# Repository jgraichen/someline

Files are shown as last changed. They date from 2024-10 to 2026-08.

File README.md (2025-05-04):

# Someline® Insets

3D printable insets for some Someline® storage boxes.

The insets can be used for small parts storage, such as screws or threaded inserts. Insets can easily be taken out, reorganized, spilled or refilled.

A label tab supports common 6 mm label printer tape.

You can find all models and print profiles on [MakerWorld](https://makerworld.com/en/collections/6267464).

## Someline box with 15 compartments

See: [MakerWorld](https://makerworld.com/en/models/706279) &middot; [Amazon](https://www.amazon.de/dp/B08GBPQJBG)

The insets have some tolerances to ease inserting and removing. Therefore, I recommend placing a few walls to balance spacing.

<table cellpadding="0">
  <tr>
    <td>
      <a href="docs/someline-15-empty.jpeg">
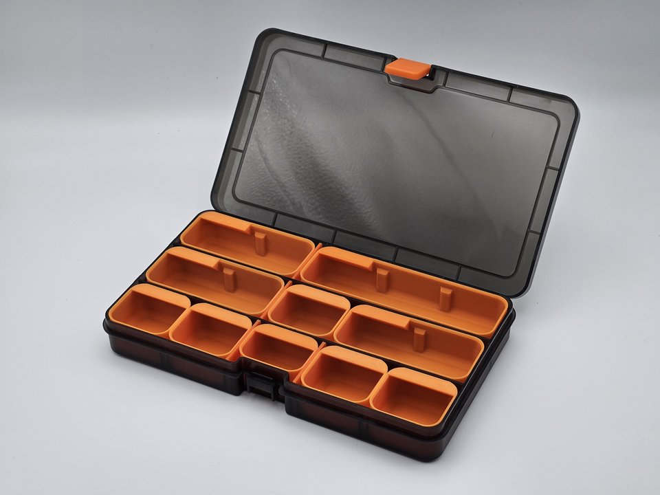
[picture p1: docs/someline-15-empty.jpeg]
        
      </a>
    </td>
    <td>
      <a href="docs/someline-15-example-1.jpeg">
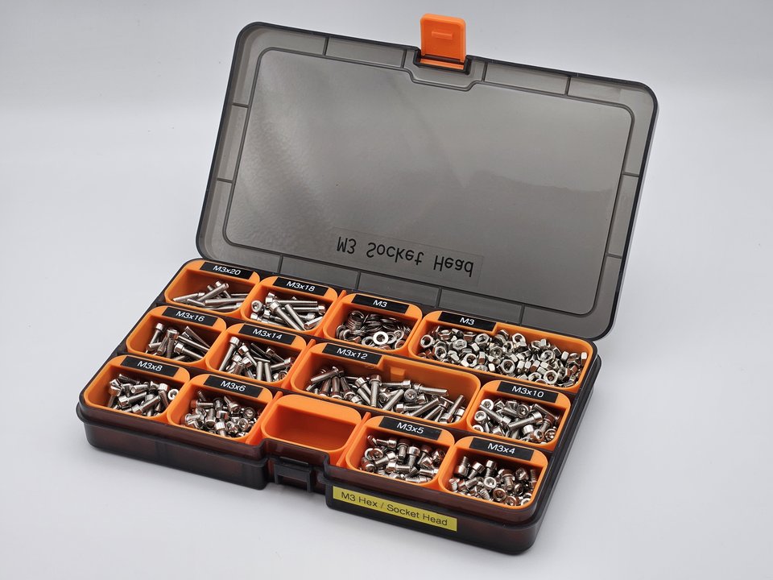
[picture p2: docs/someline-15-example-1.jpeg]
        
      </a>
    </td>
    <td>
      <a href="docs/someline-15-example-2.jpeg">
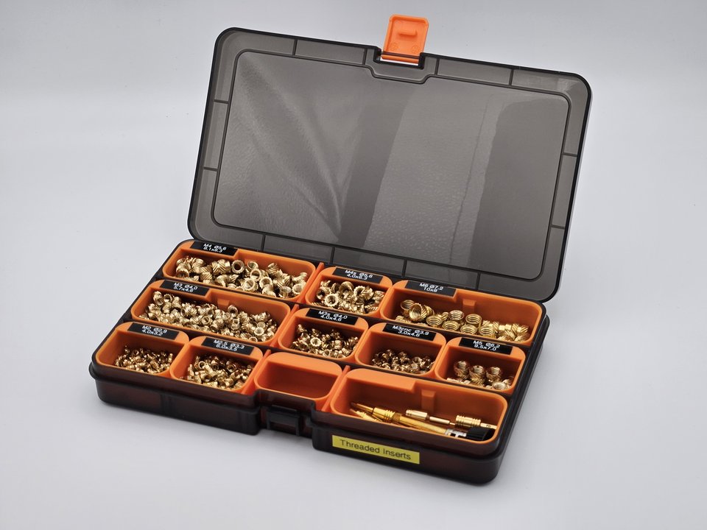
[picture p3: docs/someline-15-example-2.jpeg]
        
      </a>
    </td>
    <td>
      <a href="docs/someline-15-u.jpeg">
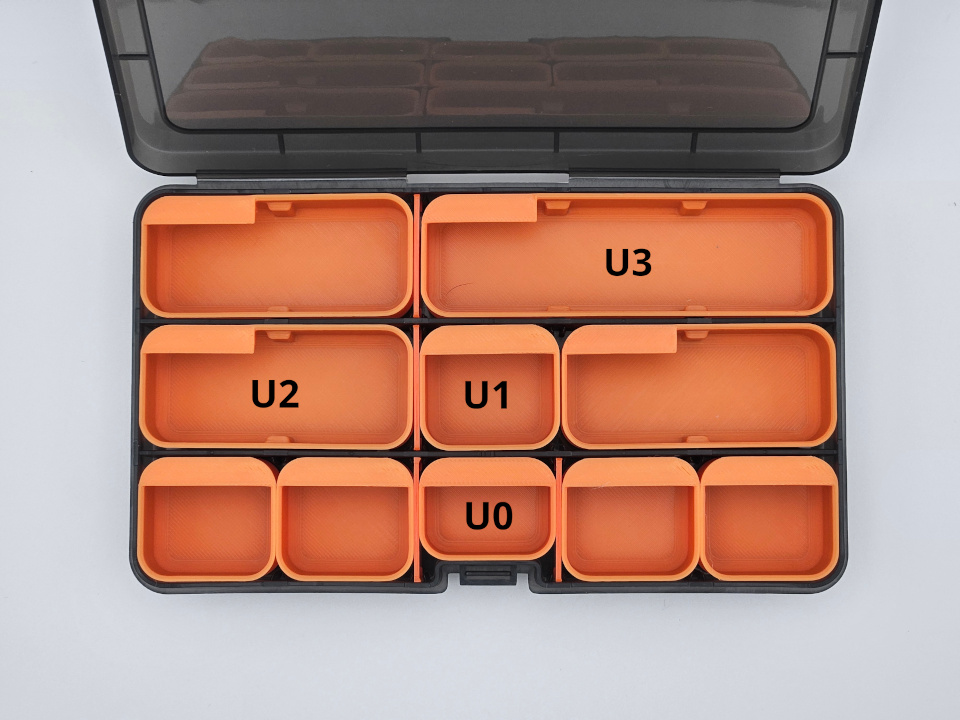
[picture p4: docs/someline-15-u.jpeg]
        
      </a>
    </td>
    <td>
      <a href="docs/someline-15-u-2.jpeg">
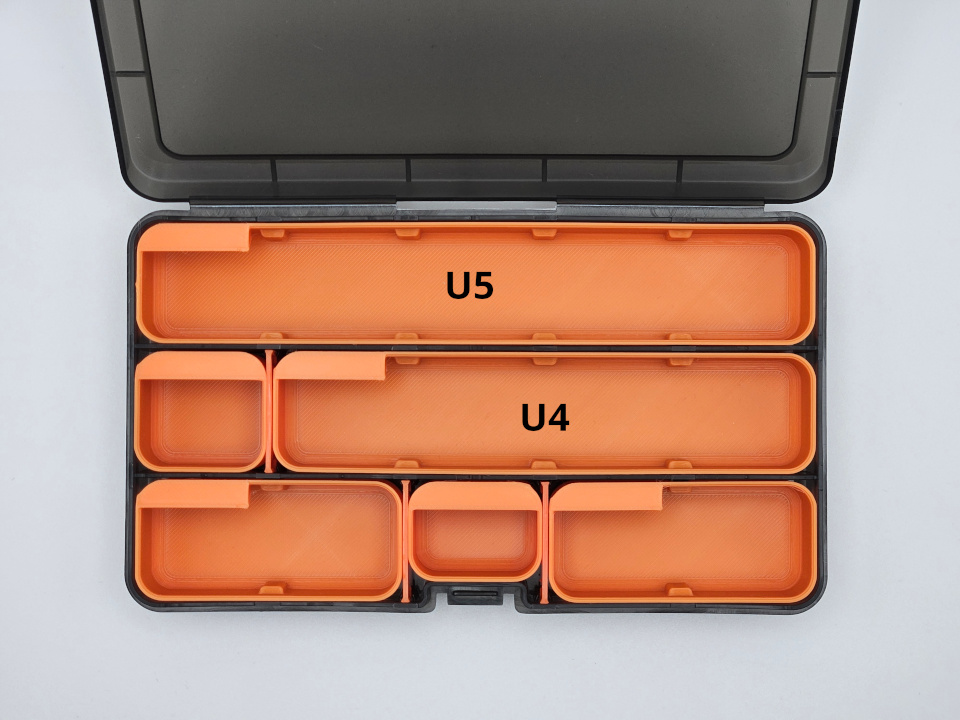
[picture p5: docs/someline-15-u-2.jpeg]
        
      </a>
    </td>
  </tr>
</table>

## Someline box with 36 compartments

See: [MakerWorld](https://makerworld.com/en/models/1383525) &middot; [Amazon](https://www.amazon.de/dp/B07RBMHPLP)

<center>
  <table cellpadding="0">
    <tr>
      <td>
        <a href="docs/someline-36.jpeg">
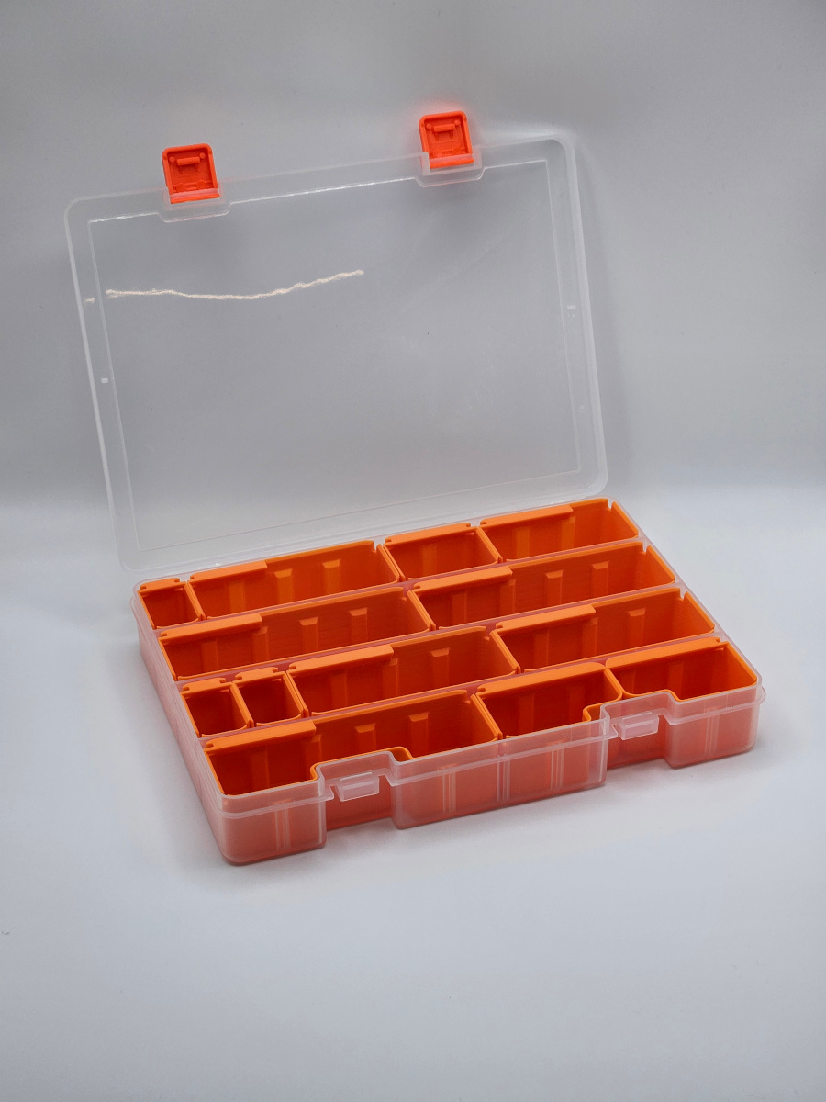
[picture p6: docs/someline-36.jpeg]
          
        </a>
      </td>
      <td>
        <a href="docs/someline-36-u.png">
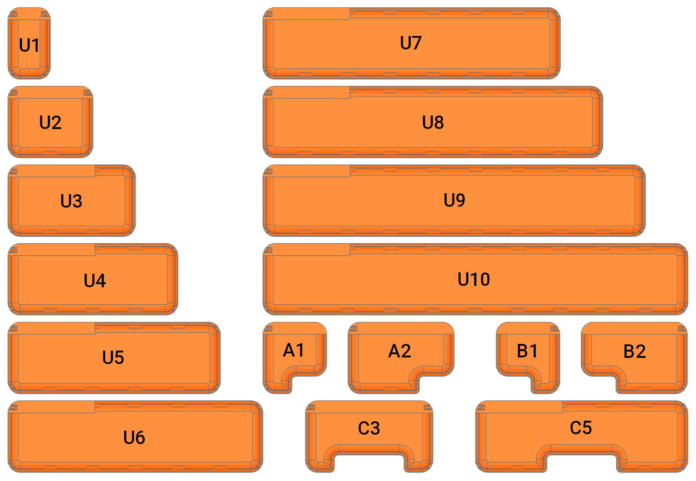
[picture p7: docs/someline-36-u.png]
          
        </a>
      </td>
    </tr>
  </table>
</center>

## Related links

* [MakerWorld Collection](https://makerworld.com/en/collections/6267464)

## License

All models, print profiles, and other files, if applicable, are licensed under [Creative Commons Attribution-ShareAlike 4.0 International License](http://creativecommons.org/licenses/by-sa/4.0/).

CC BY-SA 4.0 (http://creativecommons.org/licenses/by-sa/4.0/)

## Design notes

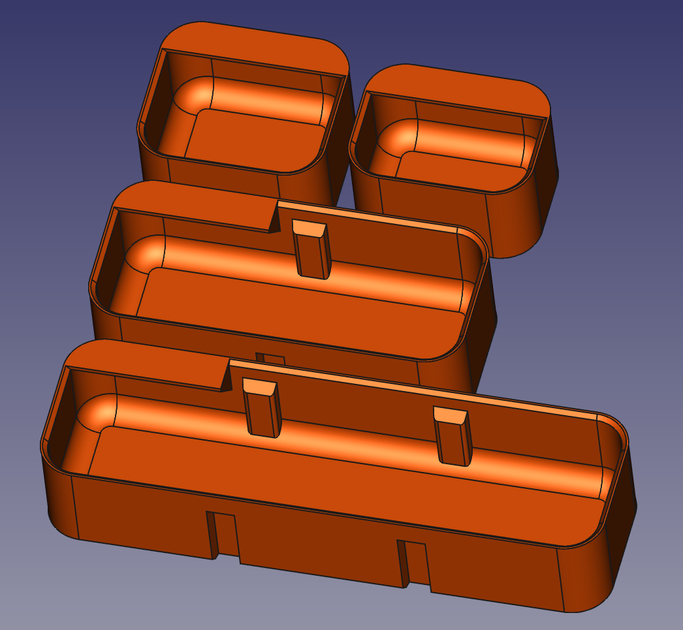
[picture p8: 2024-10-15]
docs/preview-rendering.png

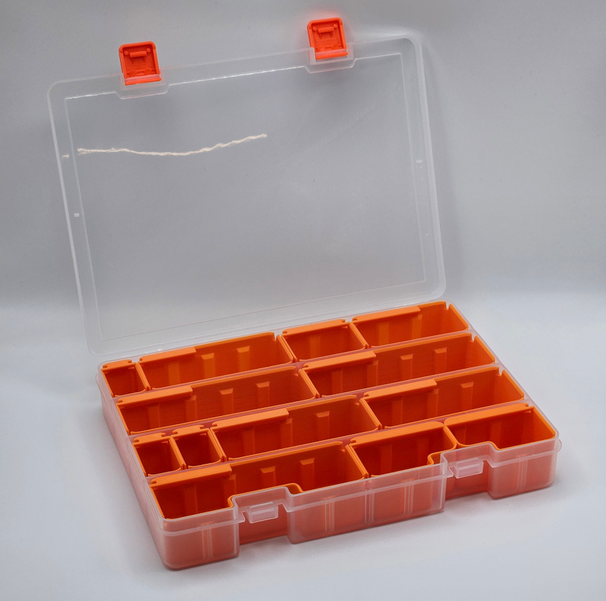
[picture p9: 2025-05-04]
docs/someline-36-a.jpeg

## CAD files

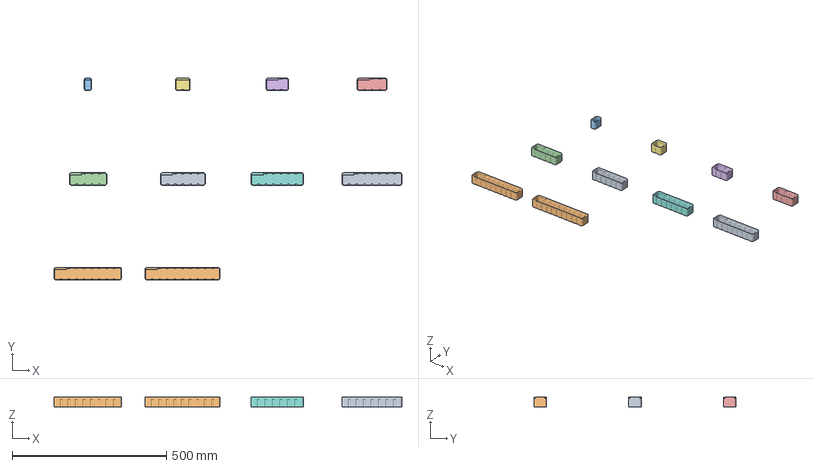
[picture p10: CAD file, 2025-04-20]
3mf/someline-36.3mf
1128.8 x 655.6 x 33.7 mm
Someline-36-U6.step
Someline-36-U10.step
Someline-36-U1.step
Someline-36-U5.step
Someline-36-U4.step
Someline-36-U3.step
Someline-36-U2.step
Someline-36-U7.step
Someline-36-U8.step
Someline-36-U9.step

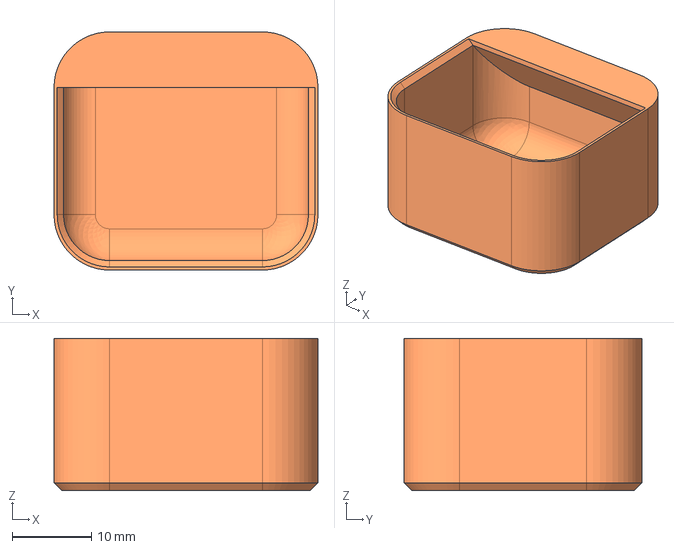
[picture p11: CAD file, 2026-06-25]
export/someline-15/U1.step
33.2 x 30.0 x 19.2 mm

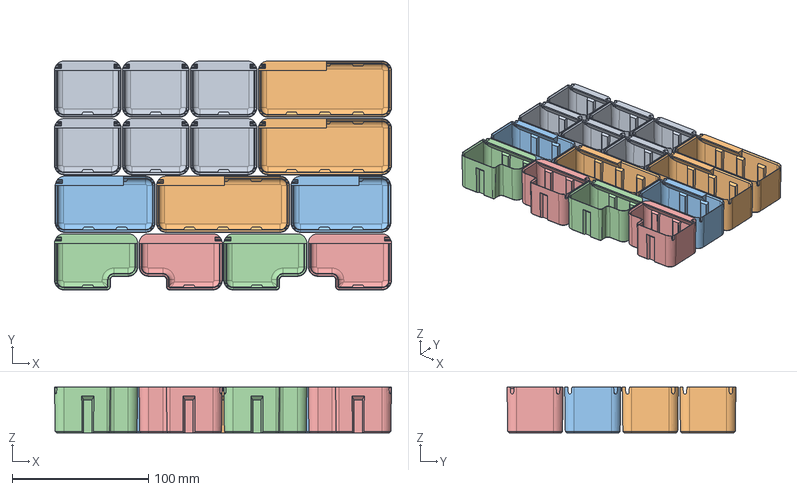
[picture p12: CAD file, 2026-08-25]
export/someline-36/plate/S.step
247.0 x 167.8 x 33.7 mm
U2 x 6
U4 x 3
U3 x 2
A2 x 2
B2 x 2

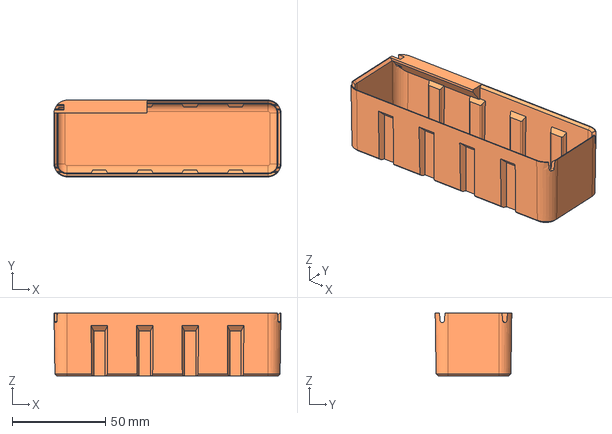
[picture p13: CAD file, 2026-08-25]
export/someline-36/U5.step
122.0 x 41.2 x 33.7 mm

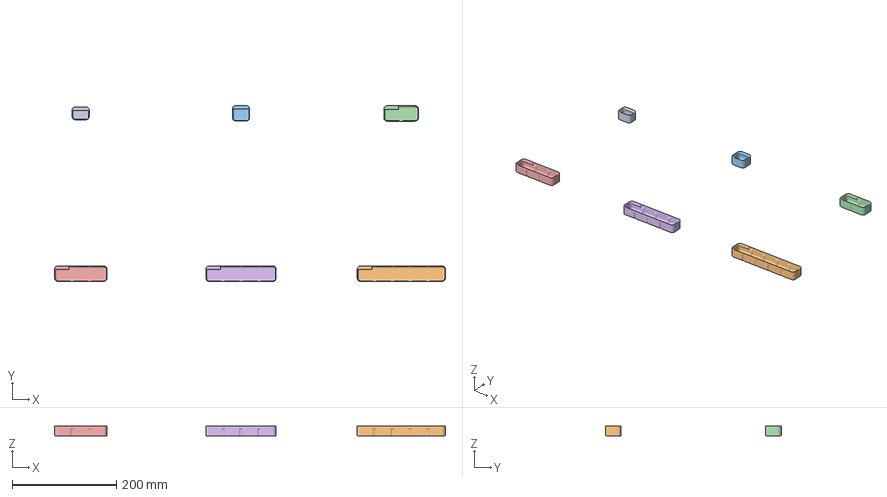
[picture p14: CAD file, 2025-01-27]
3mf/someline-15.3mf
749.2 x 337.2 x 19.2 mm
Someline-15-U0.step
Someline-15-U5.step
Someline-15-U1.step
Someline-15-U2.step
Someline-15-U3.step
Someline-15-U4.step

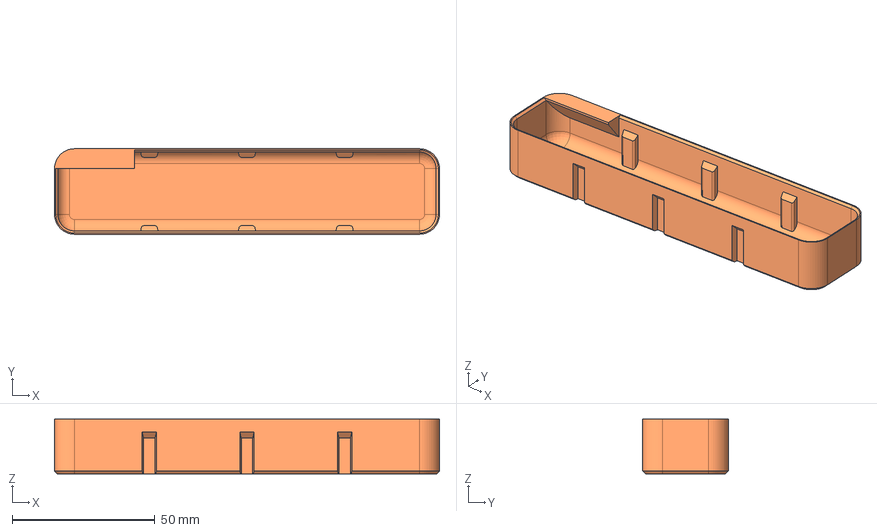
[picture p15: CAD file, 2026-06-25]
export/someline-15/U4.step
135.0 x 30.0 x 19.2 mm

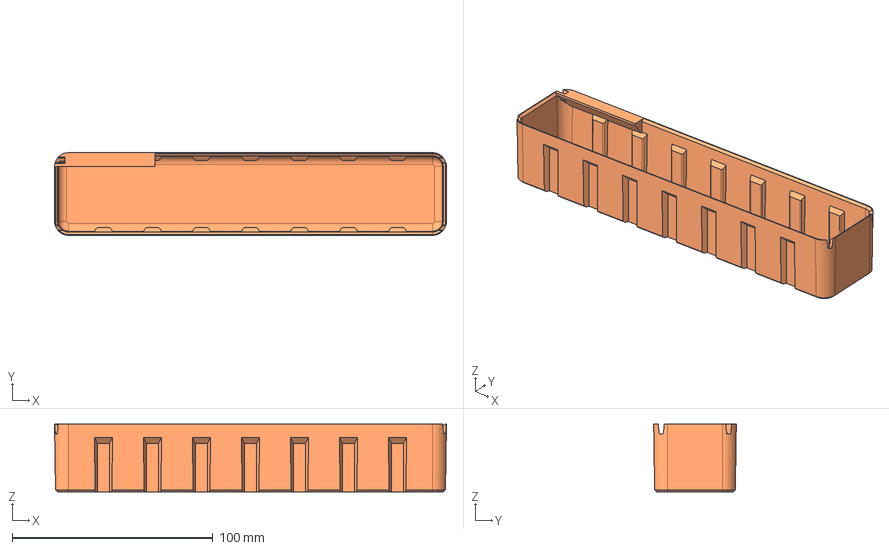
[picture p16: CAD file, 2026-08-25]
export/someline-36/U8.step
195.2 x 41.2 x 33.7 mm

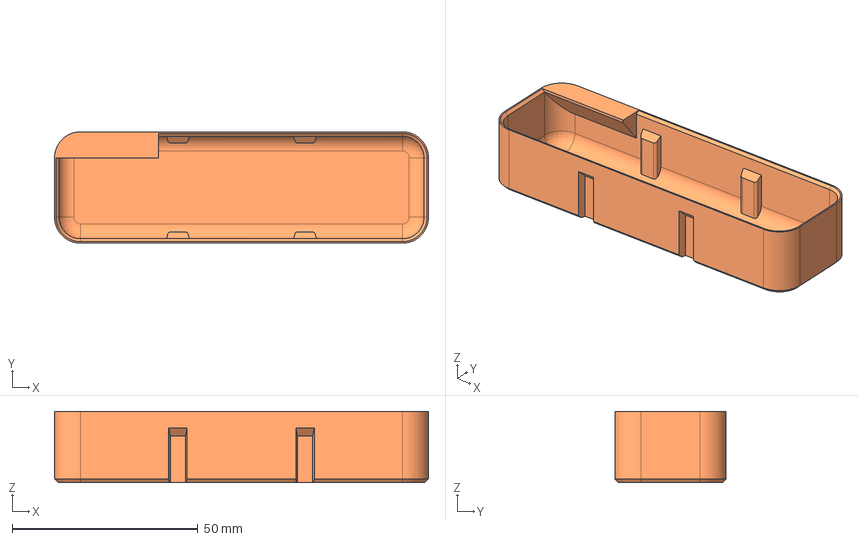
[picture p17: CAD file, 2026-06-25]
export/someline-15/U3.step
100.8 x 30.0 x 19.2 mm

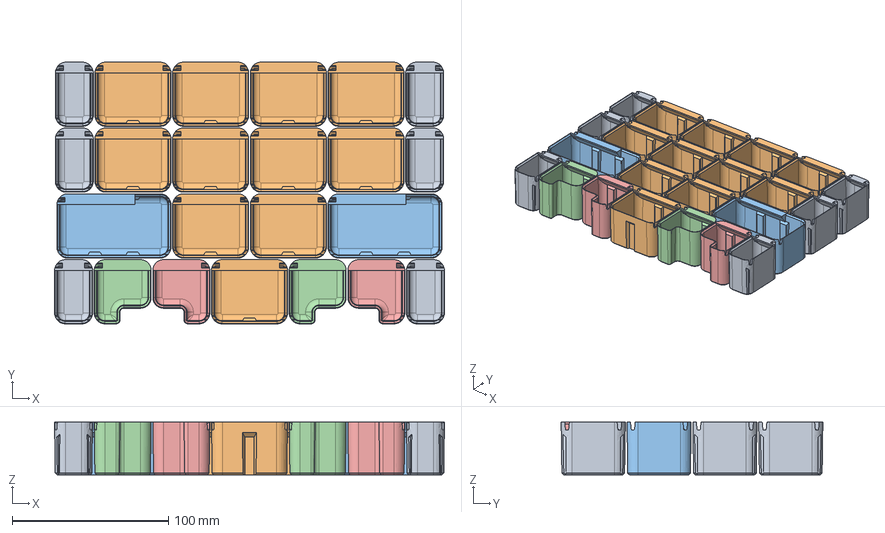
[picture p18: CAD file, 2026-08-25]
export/someline-36/plate/XS.step
250.0 x 167.8 x 33.7 mm
U1 x 6
U2 x 11
U3 x 2
A1 x 2
B1 x 2

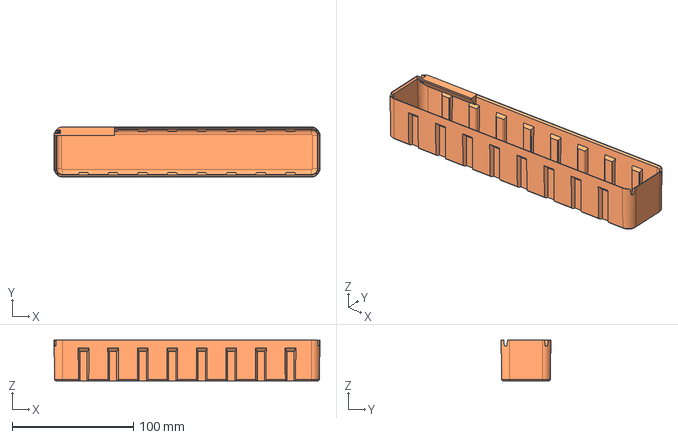
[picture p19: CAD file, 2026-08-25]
export/someline-36/U9.step
219.6 x 41.2 x 33.7 mm

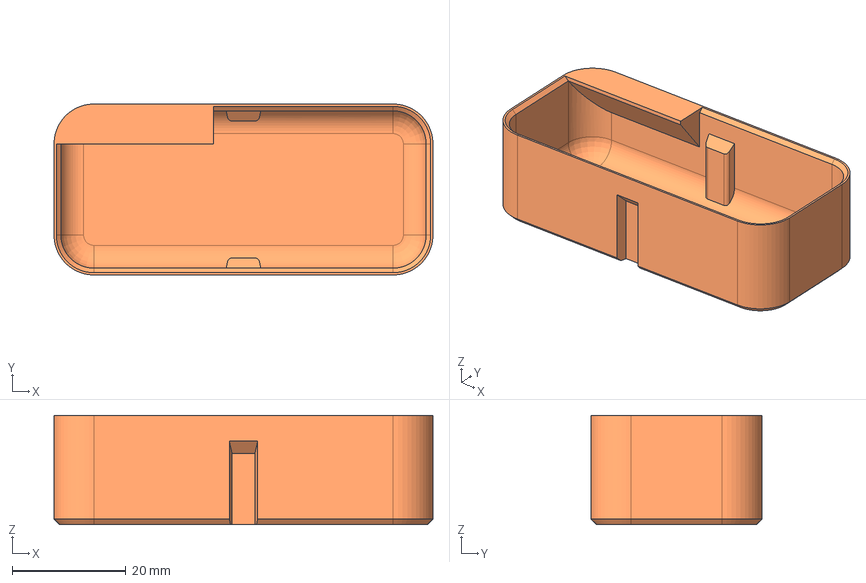
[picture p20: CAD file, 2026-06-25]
export/someline-15/U2.step
66.5 x 30.0 x 19.2 mm

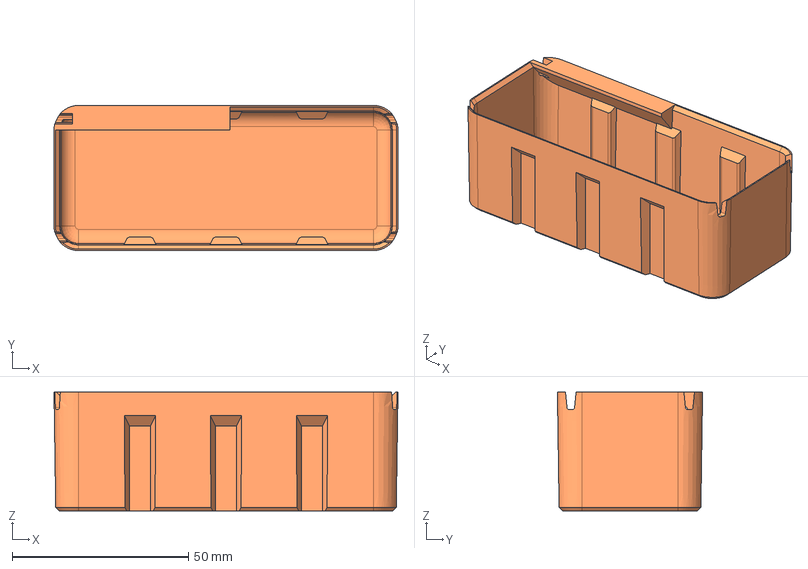
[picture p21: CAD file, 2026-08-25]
export/someline-36/U4.step
97.6 x 41.2 x 33.7 mm

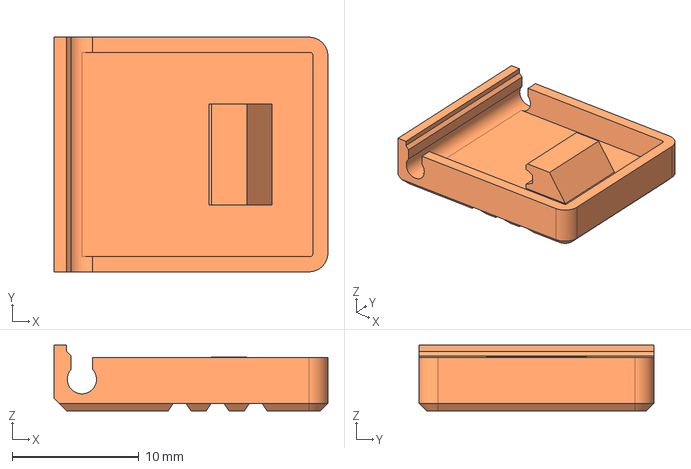
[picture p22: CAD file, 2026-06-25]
export/someline-15/cap.step
21.6 x 18.5 x 5.20 mm

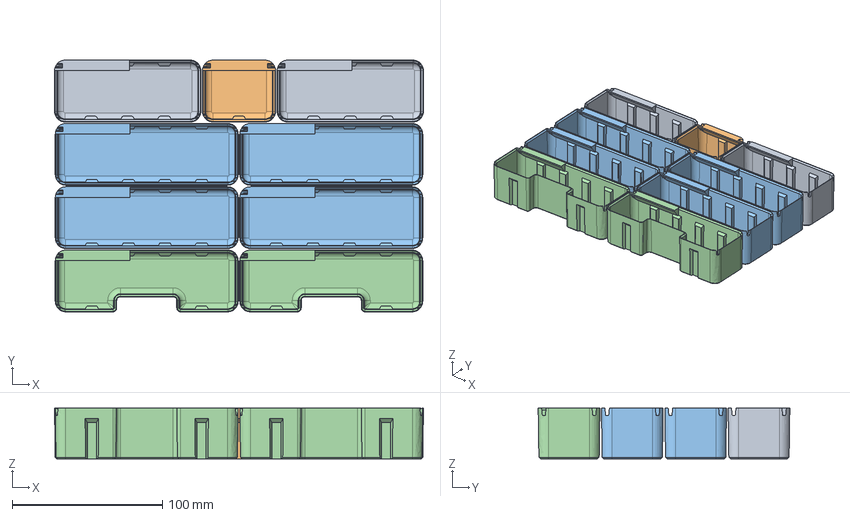
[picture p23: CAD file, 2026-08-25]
export/someline-36/plate/XL.step
246.0 x 167.8 x 33.7 mm
U4 x 2
U2
U5 x 4
C5 x 2

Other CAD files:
export/someline-36/plate/L.step
export/someline-36/plate/M.step
export/someline-36/U7.step
export/someline-15/U0.step
export/someline-15/U0.stl
export/someline-15/U1.stl
export/someline-15/U2.stl
export/someline-15/U3.stl
export/someline-15/U4.stl
export/someline-15/U5.step
export/someline-15/U5.stl
export/someline-15/cap.stl
export/someline-36/A1.step
export/someline-36/A1.stl
export/someline-36/A2.step
export/someline-36/A2.stl
export/someline-36/B1.step
export/someline-36/B1.stl
export/someline-36/B2.step
export/someline-36/B2.stl
export/someline-36/C3.step
export/someline-36/C3.stl
export/someline-36/C5.step
export/someline-36/C5.stl
export/someline-36/U1.step
export/someline-36/U1.stl
export/someline-36/U10.step
export/someline-36/U10.stl
export/someline-36/U2.step
export/someline-36/U2.stl
export/someline-36/U3.step
export/someline-36/U3.stl
export/someline-36/U4.stl
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

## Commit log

2024-10-15 Insets for Someline 15 compartment boxes
    [Someline-15-Insets-U0.step, Someline-15-Insets-U0.stl, Someline-15-Insets-U1.step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]
2024-10-27 fix: Make STEP export idempotent
    STEP files are imported from FreeCAD with a timestamp, making it
    conflict with git since there always are changes. This commit modifies
    the export script to strip the timestamp from the export.
    Therefore, if there are no model changes, exported step files will be
    identical.
    [Someline-15-Insets-U0.step, Someline-15-Insets-U1.step, Someline-15-Insets-U2.step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]
2024-10-30 Rebuild all with build123d
    [Someline-15-Insets-U0.step, Someline-15-Insets-U0.stl, Someline-15-Insets-U1.step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]
2024-10-31 feat(36): Make boxes a bit larger and movable
    Increase the cutout size so that boxes can move a little bit more to
    each side so that I can increase the width of the outermost section.
    This will slighly reduce wasted space between boxes.
    [Someline-36-U1.step, Someline-36-U1.stl, Someline-36-U2.step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]
2024-12-27 feat: Add U5 + Improve spacing on larger insets
    * Add U5 inset
    * Widen spacing (.25mm) between cutouts to better match actual spacing
    in boxes. U4 and U5 box match much better now.
    [Someline-15-U3.step, Someline-15-U3.stl, Someline-15-U4.step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]
2025-01-08 feat: Make wall width and handle width configurable
    [Someline-15-U0.step, Someline-15-U0.stl, Someline-15-U1.step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]
2025-01-08 fix(36): Cutout spacing on long insets
    Slightly increase wall size too for increased stability.
    [Someline-36-U1.step, Someline-36-U1.stl, Someline-36-U2.step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]
2025-01-27 Update 3mf and README for new 15-U4 and U5
    [someline-15.3mf]
2025-02-10 chore: Update build123d (and OCCT)
    [Someline-15-U0.step, Someline-15-U0.stl, Someline-15-U1.step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]
2025-04-20 feat: Someline36 cutouts for pin in lid
    [Someline-36-U1.step, Someline-36-U1.stl, Someline-36-U10.step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]
2025-05-01 feat: Adjust lit pin cutout for tolerances
    Increase the lit pin cutout length to avoid insets being pushed by the
    lit pin due to too small tolerances.
2025-05-01 chore: Update export models
    [Someline-36-U1.step, Someline-36-U1.stl, Someline-36-U10.step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]
2025-05-01 feat: Someline 36 C3/C5 insets for the lit cutouts
    [Someline-36-C3.step, Someline-36-C3.stl, Someline-36-C5.step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]
2025-05-01 chore: Update exports
    [Someline-36-C3.step, Someline-36-C3.stl, Someline-36-C5.step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]
2025-05-01 chore: Rework internal project definitions
    Project framework:
    * Support for project default color
    * Support for programmatic model definitions (matrix like)
    Someline:
    * Support more operations such as adding wall cutouts *inside* of
    make_box yield: This saves some extra code and extra BuildPart wraps.
    * Rename some functions and improve comments to stronger differentiate
    between the components.
2025-05-01 chore: Update model exports
    No visual changes.
    [Someline-15-U0.step, Someline-15-U0.stl, Someline-15-U1.step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]
2025-05-03 feat(util): Run multiple parts and group them as assembly
    The `run` command accepts a glob pattern now, to generate and show
    multiple models, or all, but puts them all into an assembly. The
    assembly is then spread out on the XY plane, so that parts are grouped
    nicely together and not interleaving anymore.
    [Someline-36-C3.step, Someline-36-C3.stl, Someline-36-C5.step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]
2025-05-04 36: Increase lit pin cutout to match actual pin size
2025-05-04 feat(36): Redesign sizes and box geometry
    * Use a loft box design, which is ~.5mm smaller at the bottom that on
    the top, which accounts better for perfectly vertical walls and
    tolerances on the Someline box and wall brackets.
    * The U1 box has additional pocket cutouts to account for the thinner
    row size on the outer pockets in the boxes. The wall brackets would
    collide with 7mm rounded edges otherwise.
    * Equally size all row compartments: All boxes use the same row sizing
    now, there is no difference in INNER and OUTER row size anymore.
    Therefore, no original walls inserts are needed anymore to fill in
    gaps when using many smaller insets.
2025-05-04 chore: Update model exports
    [Someline-36-A1.step, Someline-36-A1.stl, Someline-36-A2.step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]
2025-05-04 chore: Re-add missing 36-U10
    [Someline-36-U10.step, Someline-36-U10.stl]
2025-05-04 feat: Support custom grid for run assembly
    The custom grid allows a project to organize models in a specific when
    when multiple are rendered using `run`. This helps with creating
    specific compositions e.g. for screenshots.
2025-05-04 chore: Drop decorator feature and adjust naming
    Shorter naming avoids repetition between project and model name, and
    keeps the code shorted when definiting model functions.
    These all use pass function references, or partial, instead of
    decorators, to avoid confusion. partial() allows passing some arguments
    very nicely.
    This prepares the project framework to handle more variants/matrix
    builds in the future.
    [A1.step, A1.stl, A2.step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]
2025-05-04 chore: Update names in generated step files
    [A1.step, A2.step, B1.step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]
2025-05-04 fix: 36-B1 wrongly sized
    [B1.step, B1.stl]
2025-06-21 feat: Someline 15 cap
    [cap.step, cap.stl]
2025-06-21 feat(lib): Add support for compound plates
    Allow defining plates, several models organized together on one plane,
    similar to a print plate.
    Can later be exported to 3md, but for now, only a combined STEP model is
    exported.
2025-06-21 feat(36): Export plates of combinations for a full box
    Export several print plates will full sets for boxes in different sizes.
    [L.step, M.step, S.step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]
2025-11-16 chore: Update plate exports
    [L.step, M.step, S.step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]
2025-11-16 fix(pre-commit): Ignore generated files
    [L.step, M.step, S.step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]
2026-03-30 chore(deps): pin dependencies
2026-06-25 build: Update model exports after updating build123d
    [A1.step, A1.stl, A2.step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]
2026-06-25 chore: Ignore unstable plate exports in CI
    These are unstable, i.e. the files differ in CI because object get
    differently sorted and end up with different IDs.
2026-10-25 fix: make plate STEP exports reproducible
    OCCT writes the color styles of assembly parts in hash map order, which
    depends on memory addresses and changes with every run. Plates are now
    exported without colors; the plate preview keeps them.
    Plates are checked in CI again.
2026-10-25 choe: Update exports after plate stability fix
